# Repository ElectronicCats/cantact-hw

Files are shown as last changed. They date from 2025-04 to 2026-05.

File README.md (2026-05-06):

# CANtact Hardware

<p align="center">
<a href="https://github.com/ElectronicCats/cantact-hw/wiki">
    
</a>
</p>

<p align=center>
    Available at distributors:
 </p>
<p align=center>
  <a href="https://hackerwarehouse.com/product/cantact-v1-2/">
    
  </a>
</p>

<p align=center>
<a href="https://github.com/ElectronicCats/cantact-hw/wiki">
  
</a>
</p>

CANtact is a low-cost, open-source CAN bus interface hardware design, designed specifically for automotive diagnostics, industrial automation, and embedded systems development.

CANtact is a high-end CAN bus interface tool based on the original CANtact design, with optimization focused in rough order on (1) reliability, (2) ease of use, (3) cost-effectiveness, and finally (4) expandability. This results in a tool that covers many automotive and industrial use-cases, making it accessible for hobbyists and professionals alike.

As an open-source project and as a remix of the original CANtact design, it also collects inputs from various community members, and welcomes your contributions!

### FEATURES AVAILABLE ⚡🚗

* USB C, RJ45 and OBDII
* Low-cost design with open-source hardware files.
* 3D printable case files included.
* Compatible with popular CAN analysis software.
* Easy assembly with clear documentation.

## Thanks / Contributors

CANtact Hardware is a community-focused project, with major contributions from:

* Original CANtact design team
* ElectronicCats team (KiCad port, improvements, and variants)
* KiCad community for excellent open-source PCB design tools
* Open-source hardware community

### Useful References

If you don't know where to start with CAN bus communication, you may find automotive diagnostic resources and CAN bus protocol documentation useful.

You can see examples of CANtact being used in automotive diagnostics and industrial applications.

**WARNING**: Always ensure proper CAN bus termination and follow safety guidelines when working with automotive systems. Do NOT connect to live automotive systems without proper isolation.

## How to contribute 



Contributions are welcome!

Please read the document [**Contribution manual**](https://github.com/ElectronicCats/electroniccats-cla/blob/main/electroniccats-contribution-manual.md) which will show you how to contribute your changes to the project.

✨ Thanks to all our [Contributors](https://github.com/ElectronicCats/Minino/graphs/contributors)! ✨ ✨

See [**_Electronic Cats CLA_**](https://github.com/ElectronicCats/electroniccats-cla/blob/main/electroniccats-cla.md) for more information.

See the [**Community code of conduct**](https://github.com/ElectronicCats/electroniccats-cla/blob/main/electroniccats-community-code-of-conduct.md) for a vision of the community we want to build and what we expect from it.

## 3D Printed Case

Custom 3D printable case files are included in the `case/` directory:
- `CANTAC_case_top.stl` - Top cover
- `CANTAC_case_bttm.stl` - Bottom cover

## Documentation

- **Official Documentation**: [Linklayer Wiki](https://cantact.io/cantact/users-guide.html)

## Where to Buy

Ready-made CANtact devices are available from:

- 🇺🇸 [Hacker Warehouse](https://hackerwarehouse.com) (USA)

## License

This project CANtact Hardware is adapted from the original CANtact design and is licensed under CC BY-SA 4.0, "CANtact Hardware" contains modifications such as: porting the project to KiCad, modifying BOM and dimensions, and adding new variants, is licensed under CC BY-SA 4.0 by ElectronicCats.

Electronic Cats invests time and resources in providing this open-source design. Please support Electronic Cats and open-source hardware by purchasing products from Electronic Cats!

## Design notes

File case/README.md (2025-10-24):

# CANTAC Enclosure/Case/Housing description

The case is split in two pieces with a snap-first design.

- Overal measuremens: 46.5mm x 37.354 mm x 22mm

## Material recommendations

It is recommended to print on Nylon PA12 (MJF or SLS) for its high strenght, good fatigue resisteance for the snap-fits and the chemical resistance, also this material has good dimensional stability for funtional parts.

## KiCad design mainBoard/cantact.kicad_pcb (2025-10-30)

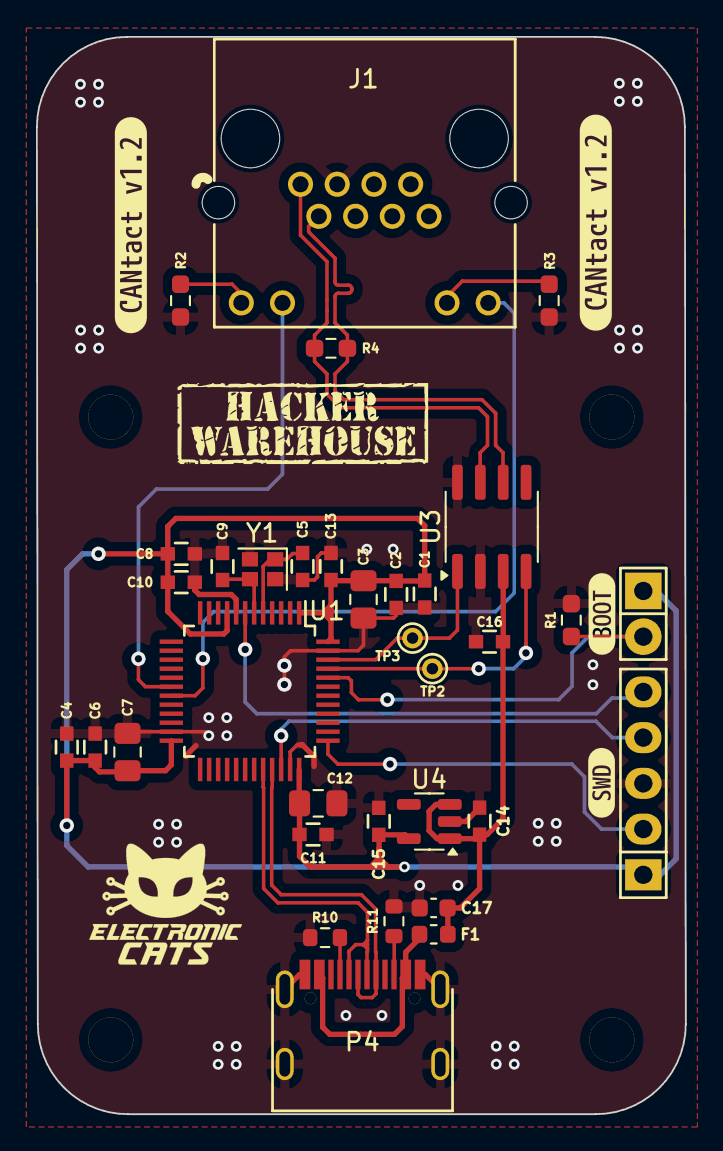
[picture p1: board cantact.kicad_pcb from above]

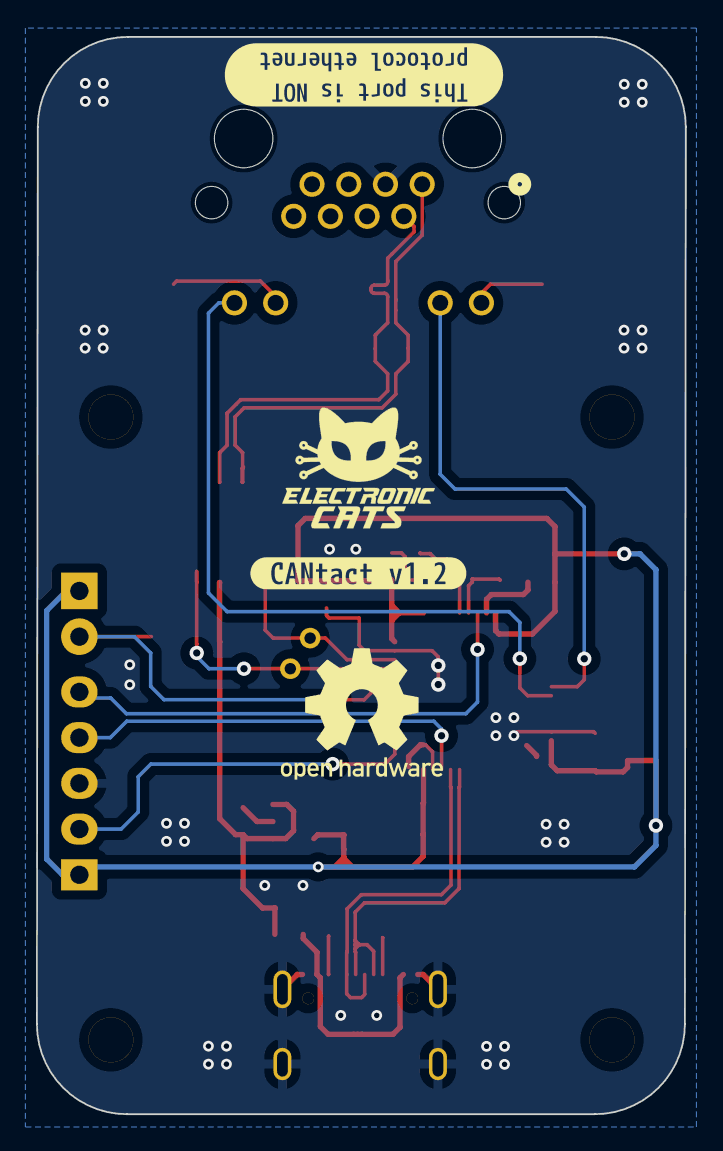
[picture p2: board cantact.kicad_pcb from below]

Board: 2 copper layers, 36.1 x 59.9 mm, 40 parts (2 on the bottom side), 22 nets.

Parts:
C1, C2, C4, C6, C11, C13, C16: 0.1uF; C_0603
C3, C7, C12: 4.7uF; C_0805_2012Metric_Pad1.18x1.45mm_HandSolder
C5, C9: 18pF; C_0603
C8: 10nF; C_0603
C10, C14, C15: 1uF; C_0603
C17: 10uF; C_0603_1608Metric
F1: 750mA; Fuse_0603_1608Metric
J1: Cantact; CONN12_R-RJ45_CKM
JP1: Boot Mode; Pin_Header_Straight_1x02
P2: SWD; Pin_Header_Straight_1x05
P4: USB_C_Plug_USB2.0; C393939
R1: 510; R_0603_1608Metric_Pad0.98x0.95mm_HandSolder
R2, R3, R4: 120; R_0603_1608Metric_Pad0.98x0.95mm_HandSolder
R10, R11: 5k1; R_0603_1608Metric
TP2, TP3: TST; PINTST
U1: STM32F042C6T6; LQFP-48_7x7mm_Pitch0.5mm
U3: MCP2551-I/SN; SOIC-8_3.9x4.9mm_P1.27mm
U4: XC6220B331MR-G; SOT-23-5
Y1: 16 Mhz; Crystal_SMD_2016-4Pin_2.0x1.6mm
kibuzzard-68FBEE71: G***; kibuzzard-68FBEE71
kibuzzard-68FBEEA6: G***; kibuzzard-68FBEEA6
kibuzzard-68FFF3A1: G***; kibuzzard-68FFF3A1
kibuzzard-68FFF3A9: G***; kibuzzard-68FFF3A9
kibuzzard-68FFF3B2: G***; kibuzzard-68FFF3B2
kibuzzard-68FFF13A: G***; kibuzzard-68FFF13A

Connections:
+3V3: C1.1, C2.1, C3.1, C4.1, C6.1, C7.1, C8.1, C10.1, C11.1, C12.1, C13.1, C15.1, JP1.1, P2.1, U1.1 (VBAT), U1.9 (VDDA), U1.24 (VDD), U1.36 (VDDIO), U1.48 (VDD), U4.5 (VOUT)
+5V: C14.1, C16.2, C17.1, F1.2, U3.3 (VDD), U4.1 (VIN), U4.3 (EN)
/CAN+: J1.1, R4.2, U3.7 (CANH)
/CAN-: J1.2, R4.1, U3.6 (CANL)
/CAN_RX: TP2.1, U1.45 (PB8), U3.4 (RXD)
/CAN_TX: TP3.1, U1.46 (PB9), U3.1 (TXD)
/D+: P4.A6 (D+), U1.33 (PA12)
/D-: P4.A7 (D-), U1.32 (PA11)
/LED_GREEN: J1.11, U1.18 (PB0)
/LED_RED: J1.9, U1.19 (PB1)
/NRST: P2.5, U1.7 (NRST)
/SWCLK: P2.2, U1.37 (PA14)
/SWDIO: P2.4, U1.34 (PA13)
GND: C1.2, C2.2, C3.2, C4.2, C5.2, C6.2, C7.2, C8.2, C9.2, C10.2, C11.2, C12.2, C13.2, C14.2, C15.2, C16.1, C17.2, J1.3, P2.3, P4.A1 (GND), P4.S1 (SHIELD), R1.2, R2.2, R3.2, R10.1, R11.1, U1.8 (VSSA), U1.23 (VSS), U1.35 (VSS), U1.47 (VSS), U3.2 (VSS), U3.8 (Rs), U4.2 (GND), Y1.2, Y1.4
unnamed: F1.1, P4.A4 (VBUS)
unnamed: J1.10, R3.1
unnamed: J1.12, R2.1
unnamed: JP1.2, R1.1, U1.44 (BOOT0-PF11)
unnamed: P4.A5 (CC), R10.2
unnamed: P4.B5 (VCONN), R11.2
unnamed: C5.1, U1.5 (PF0-OSC_IN), Y1.1
unnamed: C9.1, U1.6 (PF1-OSC_OUT), Y1.3

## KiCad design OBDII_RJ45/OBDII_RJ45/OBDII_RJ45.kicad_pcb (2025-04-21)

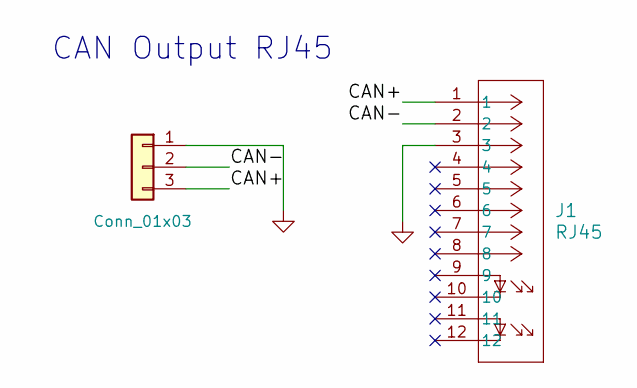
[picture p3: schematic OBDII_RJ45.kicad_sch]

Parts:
J1: RJ45; CONN12_R-RJ45_CKM; LCSC# C386757
J3: Conn_01x03; PinHeader_1x03_P2.54mm_Vertical; LCSC# C492411

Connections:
/CAN+: J1.1, J3.3
/CAN-: J1.2, J3.2
GND: J1.3, J3.1

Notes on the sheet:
CAN Output RJ45

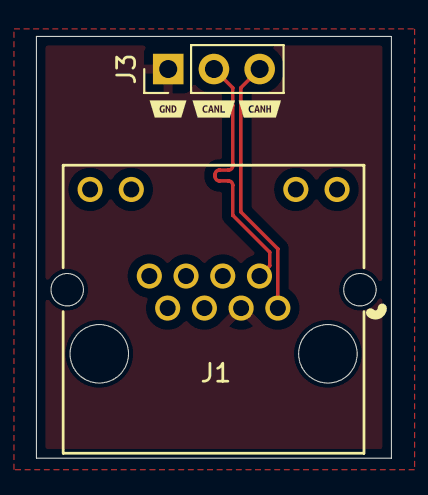
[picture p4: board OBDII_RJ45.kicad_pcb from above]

Board: 2 copper layers, 19.7 x 23.4 mm, 6 parts (1 on the bottom side), 3 nets.

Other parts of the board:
kibuzzard-67DDB05E: G***; kibuzzard-67DDB05E
kibuzzard-67DDB06D: G***; kibuzzard-67DDB06D
kibuzzard-67DDB066: G***; kibuzzard-67DDB066
kibuzzard-67FE8E6B: G***; kibuzzard-67FE8E6B

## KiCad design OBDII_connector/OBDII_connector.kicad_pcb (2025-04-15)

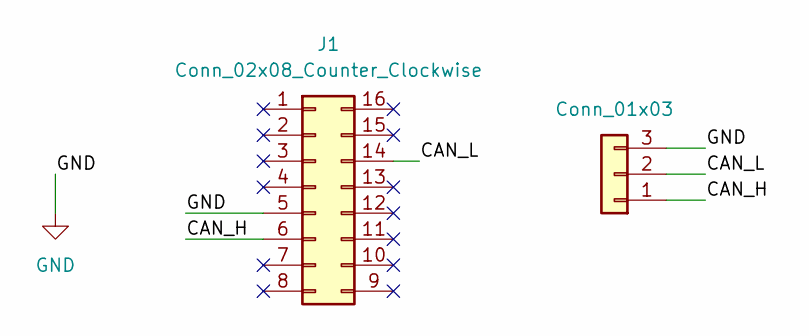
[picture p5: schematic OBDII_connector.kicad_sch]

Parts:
J1: Conn_02x08_Counter_Clockwise; OBD-II-Sparkfun v2.0
J3: Conn_01x03; PinHeader_1x03_P2.54mm_Vertical; LCSC# C541850

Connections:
/CAN_H: J1.6, J3.1
/CAN_L: J1.14, J3.2
GND: J1.5, J3.3

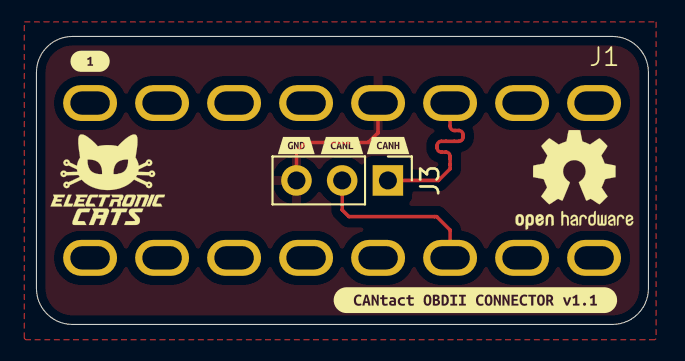
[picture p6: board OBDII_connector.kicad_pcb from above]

Board: 2 copper layers, 34.0 x 16.0 mm, 7 parts (0 on the bottom side), 3 nets.

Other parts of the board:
kibuzzard-66AA65D6: G***; kibuzzard-66AA65D6
kibuzzard-67DDAD0A: G***; kibuzzard-67DDAD0A
kibuzzard-67DDAD2E: G***; kibuzzard-67DDAD2E
kibuzzard-67DDAD71: G***; kibuzzard-67DDAD71
kibuzzard-67FE8BBD: G***; kibuzzard-67FE8BBD

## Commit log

2025-03-12 feat: rewire missing simbols
    [cantact.kicad_pcb]
2025-03-12 feat: update project to kicad 9
    [cantact-2025-03-12-14-52-35.sch, cantact.kicad_pcb, cantact.kicad_sch]
2025-03-12 feat(hw): schematic & pcb updated
    [cantact.kicad_pcb, cantact.kicad_sch]
2025-03-14 feat: replace USB & RJ45 ports
    [OBDII_connector.kicad_pcb, OBDII_connector.kicad_sch, cantact.kicad_pcb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]
2025-03-18 refactor(hw): PCB routing
    [cantact.kicad_pcb, cantact.kicad_sch]
2025-03-18 refactor(hw): tracks & vias size
    [cantact.kicad_pcb]
2025-03-19 refactor(hw): crystal position on PCB
    [OBDII_RJ45.kicad_pcb, OBDII_RJ45.kicad_sch, cantact.kicad_pcb]
2025-03-21 feat: add GND between OBDII connector & OBDII_RJ45
    [OBDII_RJ45.kicad_pcb, OBDII_RJ45.kicad_sch, OBDII_connector.kicad_pcb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]
2025-03-21 feat(hw): add lcsc parts
    [OBDII_RJ45.kicad_pcb, OBDII_connector.kicad_sch]
2025-03-28 feat(hw): move differential pair of CANH and CANL
    [cantact.kicad_pcb, cantact.kicad_sch]
2025-03-28 feat(hw): update pcb
    [cantact.kicad_pcb]
2025-03-28 refactor: 3v net & change usb resistors to front layer
    [cantact.kicad_pcb]
2025-04-18 Fix: CANbus routing and added 3D models
    [cantact.kicad_pcb, cantact.kicad_sch]
2025-04-18 fix(hw): update labels
    [cantact.kicad_pcb]
2025-04-21 Fix: CANbus routing for OBDII_RJ45
    [OBDII_RJ45.kicad_pcb, OBDII_RJ45.kicad_sch]
2025-10-23 feat(hw): add 3d files for housing
2025-10-24 fix(hw): correct STL export units
2025-10-24 feat: new paths
    [cantact-2025-03-12-14-52-35.sch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]
2025-10-27 feat: logo adjust
    [cantact.kicad_pcb]
2025-10-27 feat:update v1.2
    [cantact.kicad_pcb]
2025-10-30 fix: change footprint
    [cantact.kicad_pcb, cantact.kicad_sch]
